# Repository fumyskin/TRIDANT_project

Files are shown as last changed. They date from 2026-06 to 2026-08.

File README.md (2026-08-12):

# TRIDANT project
 
**T**wo-band **R**adiation-pattern **I**nstrument for **D**irectional **ANT**enna
characterization — a portable system that measures and visualizes 2D antenna
radiation patterns (azimuth and elevation cuts) in two bands:
 
- **GNSS L1** — ~1.575 GHz
- **V2X** — ~5.9 GHz
A hand-aimed sensor head streams raw RF power and orientation over Bluetooth Low
Energy to a host computer, which calibrates the samples, bins them by angle, and
draws live polar radiation-pattern plots.
 
> Built for the IEEE AP-S Student Design Contest.
https://photos.app.goo.gl/PjTwk66SGvRQrtHY9
---
 
## Repository layout
 
```
TRIDANT_project/
├── platformio.ini            # firmware build config (board, libs, flags)
├── src/
│   ├── main.cpp              # FreeRTOS task setup, entry point
│   └── tasks/
│       ├── ble_task.*        # NimBLE server, Sample notify
│       ├── bno_task.*        # BNO085 orientation → boresight vector
│       ├── sensor_task.*     # AD8317 ADC read
│       └── sample.h          # wire contract (byte-locked to protocol.py)
├── test/
│   └── protocol_test.cpp     # wire-format sanity checks
│
├── gui_app/
│   ├── tridant_gui.py        # live BLE GUI (matplotlib polar plots)
│   ├── capture_ble.py        # BLE → CSV logger (raw mV, re-calibratable)
│   ├── protocol.py           # Sample unpack + host-side calibration profiles
│   └── parameters.md         # per-band R_MIN/R_MAX and calibration notes
├── plotter_scripts/
│   ├── plotter.py            # offline log → polar pattern plots
│   └── interpolation_AD.py   # interpolation experiments
├── scripts/
│   └── logger.sh             # serial (USB) → band-split log files
├── 3d_models/                # printing models for the components used in the demo
│
├── logs/      logs_ble/      # captured sessions (serial / BLE)
└── plots/                    # rendered pattern figures
``` 
---
 
## How it works
 
The firmware stays deliberately thin: it emits **raw sensor values only** — the
AD8317 detector output in millivolts plus a quaternion-derived boresight
orientation. All calibration, coordinate transformation, and visualization live
**host-side**, in Python. This keeps captured logs re-calibratable after the
fact and means changing bands never requires reflashing.
 
```
  ┌─────────────────────────┐        BLE          ┌──────────────────────────┐
  │  ESP32-C6 (CodeCell)    │   15-byte Sample    │  Host (Python)           │
  │                         │  ───────────────▶  │                          │
  │  BNO085 IMU  → orient.  │  phi, theta, elev,  │  calibrate mV → dBm      │
  │  AD8317 LPD  → mV       │  mv, cal            │  bin by angle → polar    │
  └─────────────────────────┘                     │ live plot / CSV / offline│
                                                  └──────────────────────────┘
```
The wire format is a single source of truth shared across the language boundary (`src/tasks/sample.h` on the firmware side, `gui_app/protocol.py` on the host side), verified with `static_assert` in C++ and `struct.calcsize` in Python:
 
```cpp
struct Sample { float phi, theta, elev;  uint16_t mv;  uint8_t cal; }  // 15 bytes
protocol.SAMPLE_FMT = "<fffHB"                                          // 15 bytes
```

---

## Prerequisites
 
- **Firmware:** [PlatformIO](https://platformio.org/) (CLI or the VS Code
  extension). A CodeCell / ESP32-C6 board on a USB port (e.g. `/dev/ttyACM0`).
- **Host tooling:** Python 3.9+ and a working BLE adapter.

---

## Repository Installation

Clone the repository:
 
```bash
git clone https://github.com/fumyskin/TRIDANT_project.git
cd TRIDANT_project
```
 
---

The repo has two independent halves — set up whichever you need.
 
### 1. Firmware (PlatformIO)
 
`platformio.ini` pins the board (`esp32-c6-devkitm-1`), the pioarduino
ESP32 platform, and the required libraries (NimBLE-Arduino, CodeCell), so the
dependencies install themselves on the first build.
 
```bash
pip install platformio          # skip if you use the VS Code extension
 
pio run                         # build (downloads libs on first run)
pio run -t upload               # flash over USB
pio device monitor              # serial monitor @ 115200
```

### 2. Host tooling (Python)
 
Use a virtual environment so the dependencies stay isolated:
 
```bash
python -m venv .venv
source .venv/bin/activate        # Windows: .venv\Scripts\activate
 
pip install -r requirements.txt
```
 
---
 
## Usage
### Live pattern GUI
 
Real-time polar plots over BLE. Scans for the sensor head, connects, and draws
azimuth and elevation cuts as you sweep.
 
```bash
python gui_app/tridant_gui.py
```
 
Keys: `c` clears the accumulated pattern, `q` quits.

### Capture raw samples over BLE
 
Logs raw wire values (mV, not dBm) to CSV so the session stays re-calibratable
and re-plottable later.
 
```bash
python gui_app/capture_ble.py                      # timestamped CSV
python gui_app/capture_ble.py -o dipole_az.csv     # explicit file
python gui_app/capture_ble.py --dbm --band GNSS    # add dBm column + live peak
```

### Capture over serial (USB)
 
Logs the CodeCell's serial output into band-specific files under `logs/`.
Run it from inside `scripts/` (the default log directory is `../logs`):
 
```bash
cd scripts
./logger.sh GNSS                 # fallback band = GNSS
./logger.sh V2X /dev/ttyACM0     # explicit port
```
 
### Plot a captured log offline
 
```bash
python plotter_scripts/plotter.py logs/GNSS.log --normalize
python plotter_scripts/plotter.py logs/GNSS.log logs/V2X.log
```
 
---
## Calibration & configuration
 
Calibration is host-owned. Per-band detector profiles (slope in mV/dB and
intercept in mV) live in `gui_app/protocol.py`:
 
```python
PROFILES = {
    "GNSS_1G575": {"slope_mv_per_db": -25.0, "intercept_mv": 510.0},
    "V2X_5G9":    {"slope_mv_per_db": -25.0, "intercept_mv": 608.0},
}
```
 
The conversion is `P_dBm = (mv − intercept_mv) / slope_mv_per_db`. For
**normalized** pattern shape, intercept errors cancel and only the slope
matters; a **fixed absolute** radial axis additionally needs a calibrated
intercept and a known peak power.
 
To set the radial limits (`R_MIN` / `R_MAX`) for a band, find the peak by
sweeping the main beam with `capture_ble.py --dbm --band <BAND>` and reading the
live `peak` value. See **`gui_app/parameters.md`** for the full per-band
procedure and the current tuning values.
 
---
 
## Wire protocol
 
| Field | Type | Meaning |
|---|---|---|
| `phi` | float32 | azimuth (deg) |
| `theta` | float32 | polar/elevation angle (deg) |
| `elev`  | float32 | elevation (deg) |
| `mv` | uint16 | AD8317 detector output (millivolts)  |
| `cal` | uint8 | IMU calibration status |
 
Packed little-endian as `"<fffHB"` = **15 bytes**. Any change here must be made
in both `src/tasks/sample.h` and `gui_app/protocol.py`, or the two sides will
disagree.
 
---
 
## License

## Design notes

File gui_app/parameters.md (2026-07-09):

# PARAMETERS FOR CORRECT USAGE OF GUI ON GNSS AND V2X

# FINDING R_MIN, R_MAX
 1) GNSS: run `python capture_ble.py --dbm --band GNSS`, perform a complete azimuth sweep and check the `peak` value : that's your `R_MAX` to be inserted in the `tridant_gui.py`
 2) V2X: run `python capture_ble.py --dbm --band V2X`, perform a perform a complete azimuth sweep and check the `peak` value : that's your `R_MAX` to be inserted in the `tridant_gui.py`

## GNSS
`capture_ble.py`:
 1) set `DEFAULT_PROFILE` to `"GNSS_1G575"`

`tridant_gui.py`:
 1) set `PROFILE` to `"GNSS_1G575"`
 2) set `R_MAX = -5.5`  and `R_MIN = -60.0`
 3) set proper GNSS calibration based on the LPD model used:
    if ADP317: slope = -22 mv/db; intercept = 315 mv
    if ADP318: 

## V2X
`capture_ble.py`:
 1) set `DEFAULT_PROFILE` to `"V2X_5G9"`

`tridant_gui.py`:
 1) set `PROFILE` to `"V2X_5G9"`
 2) set `R_MAX = `  and `R_MIN = -60.0` 
 3) set proper GNSS calibration based on the LPD model used:
    ADP317: slope = -22 mv/db; intercept = 352 mv
    ADP318:

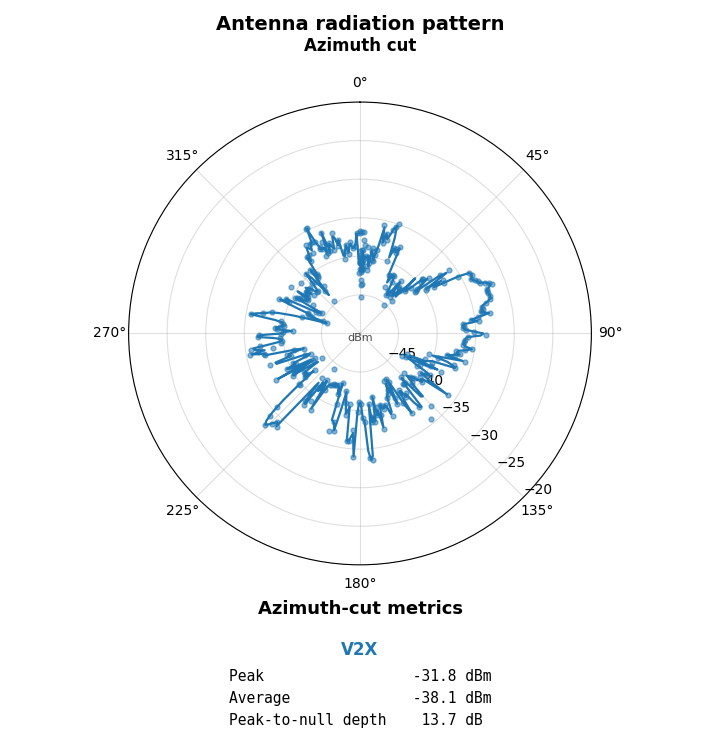
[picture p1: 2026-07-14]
plots/batch_final2/V2X_01vcutv.png

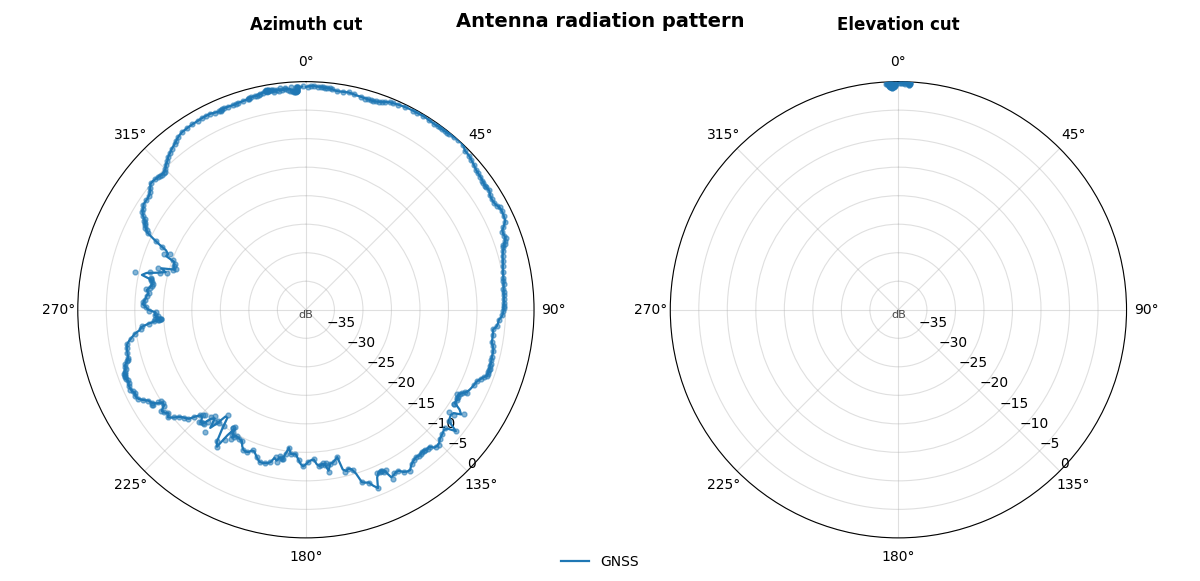
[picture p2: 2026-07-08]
plots/batch2/GNSS_03v.png

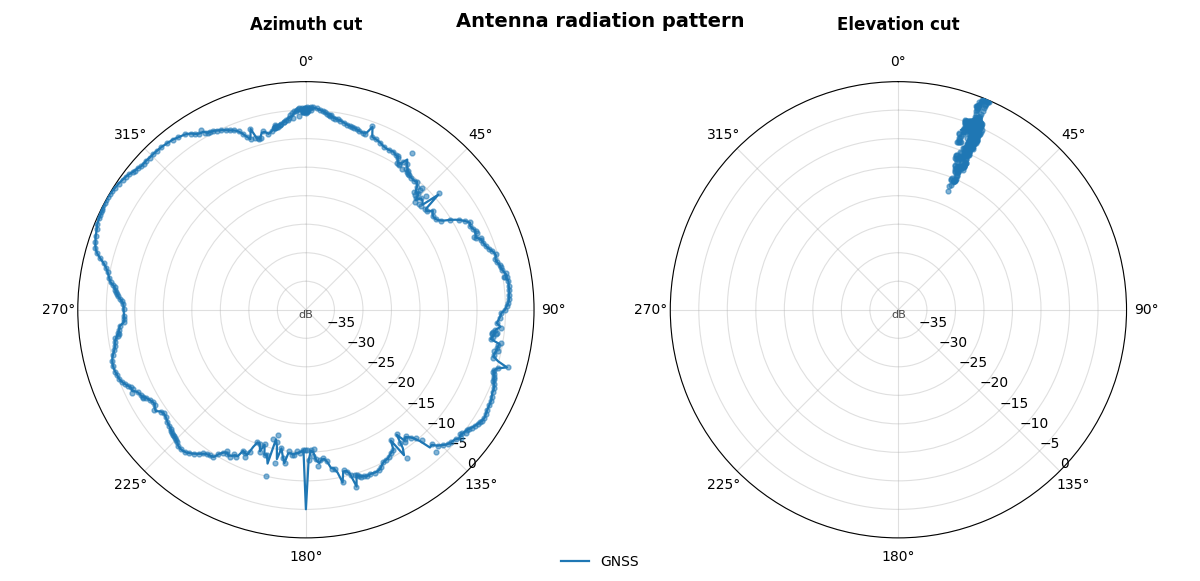
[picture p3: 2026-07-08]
plots/batch2/GNSS_02h.png

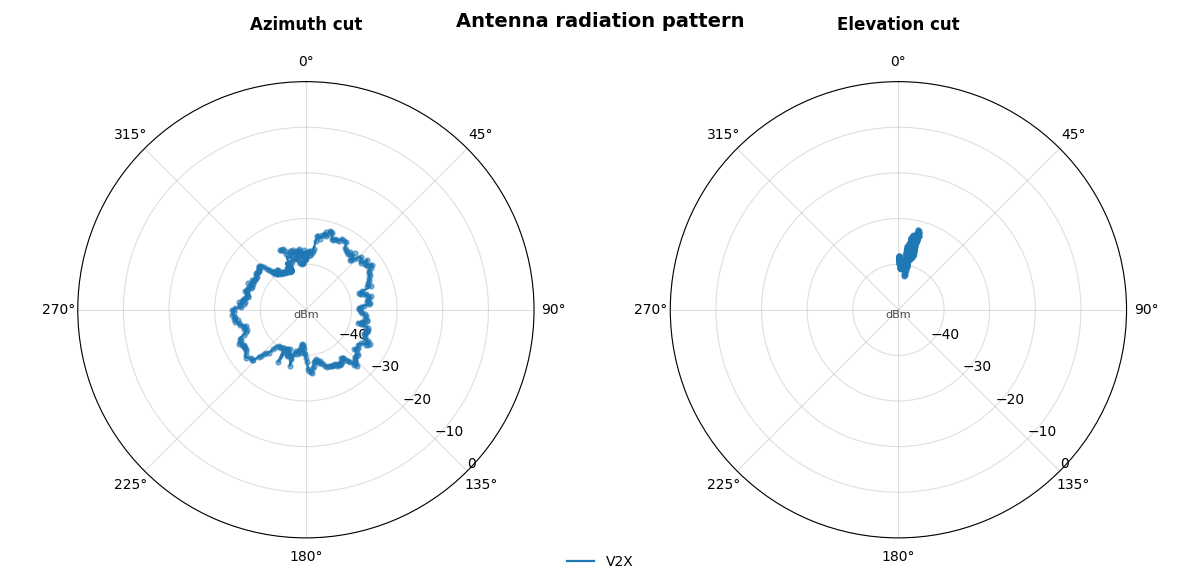
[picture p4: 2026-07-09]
plots/batch_final1.5/V2Xhcutv.png

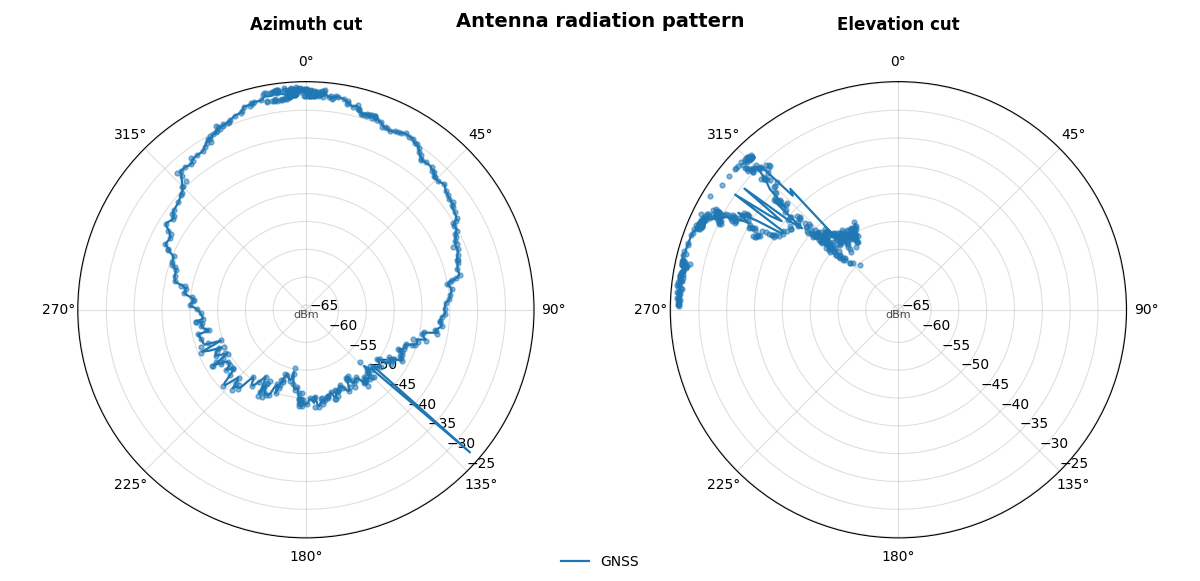
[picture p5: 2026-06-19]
plots/batch1/GNSS_04_nhc_elevation_full.png

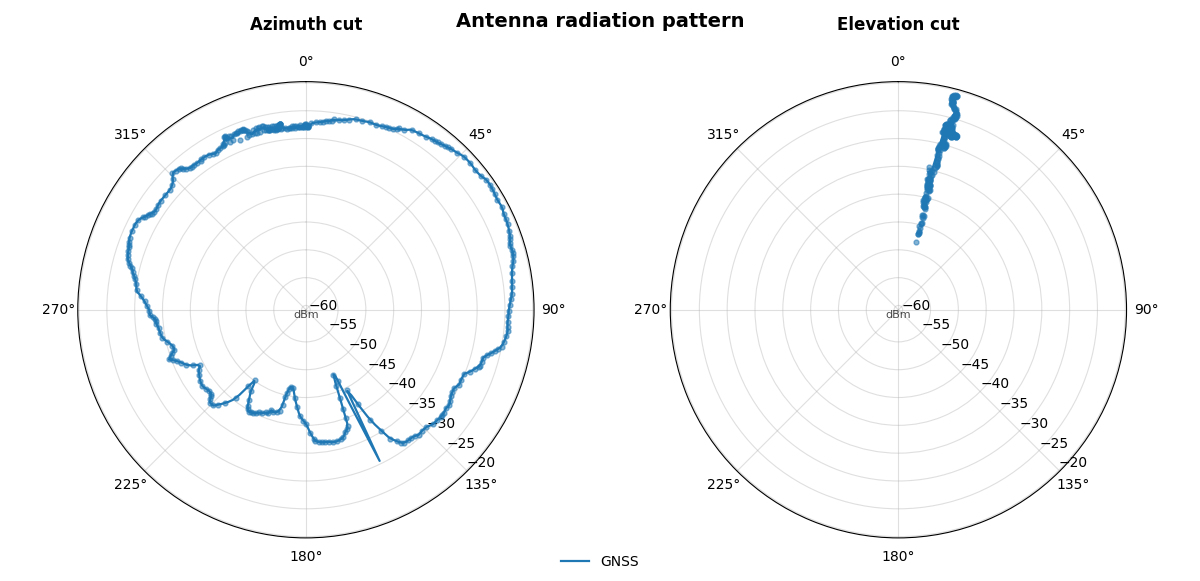
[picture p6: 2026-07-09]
plots/batch_final/GNSS_06h.png

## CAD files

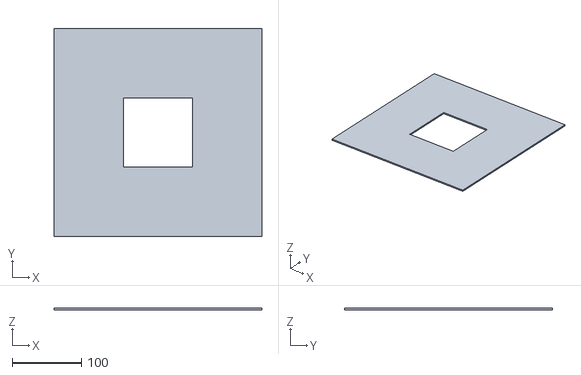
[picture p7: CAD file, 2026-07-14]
3d_models/DRA_GROUNDPLANE.stl
300.0 x 300.0 x 2.50

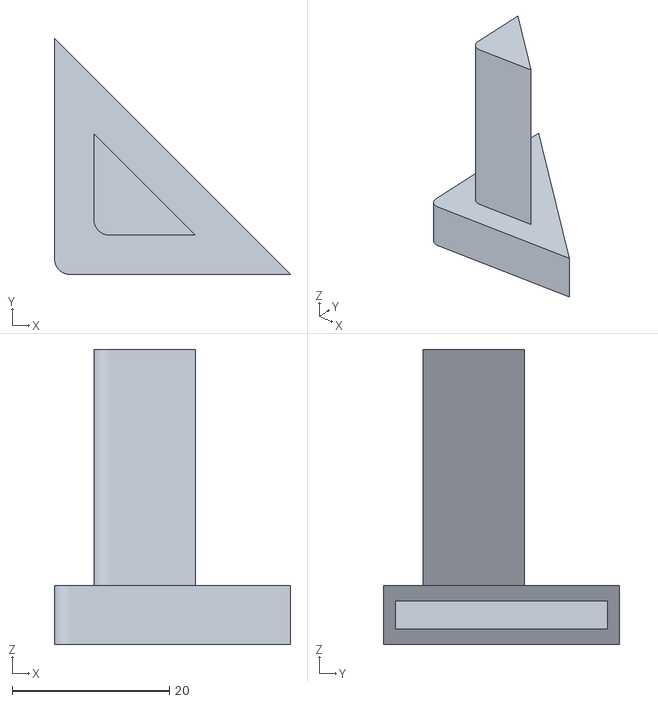
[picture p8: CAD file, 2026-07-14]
3d_models/DRA_SUPPORT.stl
30.0 x 30.0 x 37.5

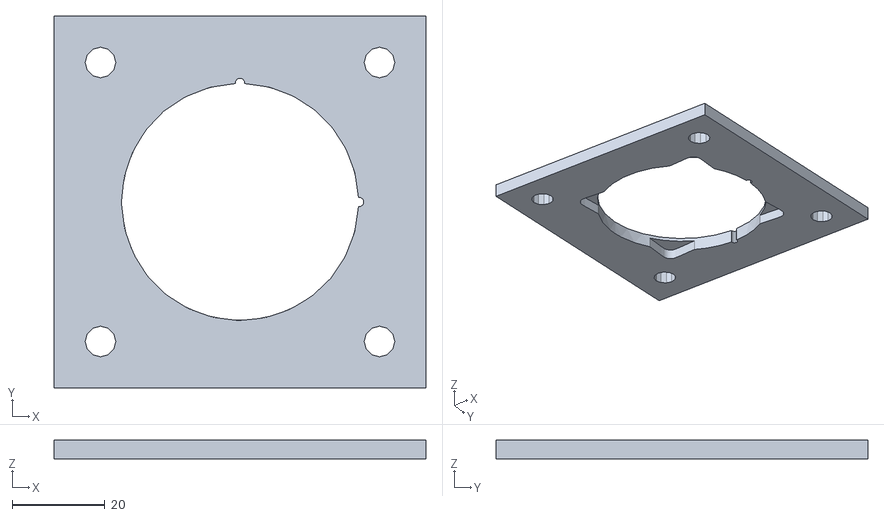
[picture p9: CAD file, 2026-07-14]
3d_models/DRA_FIXING_PLATE.stl
80.0 x 80.0 x 4.00

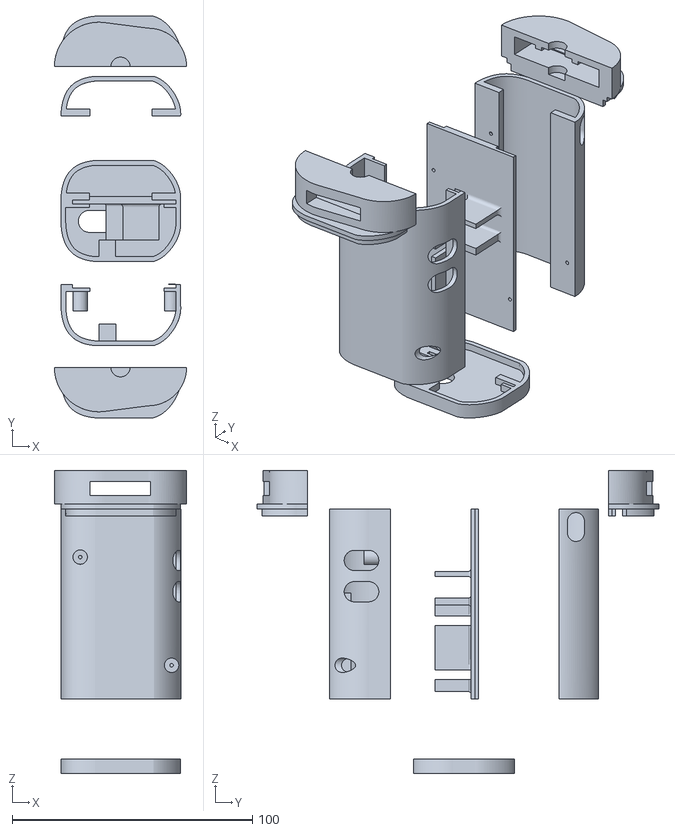
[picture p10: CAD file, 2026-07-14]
3d_models/ANTENNA_RECEIVER_HANDLE.stl
55.0 x 167.0 x 126.0

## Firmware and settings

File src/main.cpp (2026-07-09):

#include <Arduino.h>
#include <tasks/sensor_task.h>
#include "tasks/bno_task.h"
#include "tasks/ble_task.h"
#include <CodeCell.h>
#include <Wire.h>

// might be redundant
//constexpr float LPD_SLOPE_MV_PER_DB = -25.0f; // mV/dBm
//constexpr float LPD_INTERCEPT_MV    = 500.0f; //mV

//static float mv_to_dbm(int mv) {
//    return ((float)mv - LPD_INTERCEPT_MV) / LPD_SLOPE_MV_PER_DB;
//}

BnoSample ang;

void setup() {
    Serial.begin(115200);
    delay(2000);
    Serial.println("BOOT");

    sensor_task_start();
    bno_task_init();
    bno_task_calibrate(8000, 3);   // ~8 s DEAD STILL on a table — gyro ZRO settles here
    bno_task_capture_zero();
    bno_task_start();

    ble_task_start(); // create task + queue
    ble_task_setup_ble(); // build service + characteristic
    ble_task_start_advertising(); // go discoverable

    Serial.println("tasks started");
    Serial.println("phi_deg,theta_deg,elev_deg,P_dBm,mv,cal");   // <- added ,cal
}

void loop() {
    int mv = 0;
    bool haveP   = sensor_task_get_latest_mv(&mv);
    bool haveAng = bno_task_get_latest(&ang);
    uint32_t acc = bno_task_cal_accuracy();

    //remove mv_to_dbm for correct measurenments
    if (haveP && haveAng) {
        Serial.printf("%.1f,%.1f,%.1f,%d,%u\n",
                      ang.azimuth_deg,
                      ang.polar_deg,
                      ang.elevation_deg,
                      mv,
                      acc);
        if (ble_task_has_clients()){
            Sample s;
            s.phi_deg = ang.azimuth_deg;
            s.theta_deg = ang.polar_deg;
            s.elev_deg = ang.elevation_deg;
            s.mv = (uint16_t)mv;
            s.acc = (uint8_t)acc;
            ble_task_send_sample(s);
        }
    } else {
        Serial.printf("waiting: haveP=%d haveAng=%d cal=%u\n", haveP, haveAng, acc);
    }
    delay(100);   // ~10 Hz logging, matches the BNO Run(10) rate
}

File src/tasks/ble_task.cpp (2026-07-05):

#include "ble_task.h"
#include <Arduino.h>
#include <NimBLEDevice.h>
#include <freertos/FreeRTOS.h>
#include <freertos/task.h>
#include <freertos/queue.h>

#define MAX_CONNECTIONS 1
#define SERVICE_UUID        "97dcc426-d11e-476e-95e2-79f064720640"
#define CHARACTERISTIC_UUID "aae3a4f0-8e88-4bd0-8047-c6a8c2312a3d"
#define DEVICE_NAME         "TRIDANT"   

namespace {
    NimBLEServer*         pServer = nullptr;
    NimBLECharacteristic* pChar   = nullptr;
    NimBLEAdvertising*    pAdv     = nullptr;

    TaskHandle_t  bleTaskHandle = nullptr;
    QueueHandle_t bleQueue      = nullptr;

    uint16_t connIDs[MAX_CONNECTIONS];
    volatile int connCount = 0;

    enum BleCommand : uint8_t {
        BLE_START_SETUP,
        BLE_START_ADV,
        BLE_STOP_ADV,
        BLE_TX
    };

    // One message type flows through the queue. `sample` is meaningful
    // only for BLE_TX; lifecycle commands ignore it.
    struct BleMsg {
        BleCommand cmd;
        Sample     sample;
    };
}

class ServerCallbacks : public NimBLEServerCallbacks {
    void onConnect(NimBLEServer* server, NimBLEConnInfo& connInfo) override {
        uint16_t conn_id = connInfo.getConnHandle();
        if (connCount < MAX_CONNECTIONS) connIDs[connCount++] = conn_id;
        Serial.printf("Client connected, conn id: %u\n", conn_id);
        // No re-advertise here: single slot stays quiet once connected.
    }

    void onDisconnect(NimBLEServer* server, NimBLEConnInfo& connInfo, int reason) override {
        uint16_t conn_id = connInfo.getConnHandle();
        for (int i = 0; i < connCount; i++) {
            if (connIDs[i] == conn_id) {
                for (int j = i; j < connCount - 1; j++) connIDs[j] = connIDs[j + 1];
                connCount--;
                break;
            }
        }
        Serial.printf("Client disconnected (reason %d), conn id: %u\n", reason, conn_id);
        NimBLEDevice::startAdvertising();   // allow reconnect between sweeps
    }
};

static void bleTask(void* parameter) {
    NimBLEDevice::init(DEVICE_NAME);
    pServer = NimBLEDevice::createServer();
    pServer->setCallbacks(new ServerCallbacks());

    NimBLEService* pService = nullptr;
    BleMsg msg;

    for (;;) {
        if (xQueueReceive(bleQueue, &msg, portMAX_DELAY) != pdTRUE) continue;

        switch (msg.cmd) {
            case BLE_START_SETUP:
                pService = pServer->createService(SERVICE_UUID);
                pChar = pService->createCharacteristic(
                    CHARACTERISTIC_UUID,
                    NIMBLE_PROPERTY::READ | NIMBLE_PROPERTY::NOTIFY
                );
                pService->start();
                pAdv = NimBLEDevice::getAdvertising();
                pAdv->addServiceUUID(SERVICE_UUID);
                pAdv->enableScanResponse(false);
                break;

            case BLE_START_ADV:
                Serial.println("BLE_START_ADV");
                NimBLEDevice::startAdvertising();
                break;

            case BLE_STOP_ADV:
                Serial.println("BLE_STOP_ADV");
                NimBLEDevice::stopAdvertising();
                break;

            case BLE_TX:
                if (pChar && connCount > 0) {
                    pChar->setValue((uint8_t*)&msg.sample, sizeof(Sample));
                    pChar->notify();
                }
                break;
        }
    }
}

// ---- public API ----
void ble_task_start() {
    bleQueue = xQueueCreate(8, sizeof(BleMsg));
    xTaskCreate(bleTask, "BLE Task", 4096, nullptr, 1, &bleTaskHandle);
}

void ble_task_setup_ble() {
    BleMsg m{ BLE_START_SETUP, {} };
    xQueueSend(bleQueue, &m, portMAX_DELAY);
    Serial.println("Setting up the BLE");
    delay(1);
}

void ble_task_start_advertising() {
    BleMsg m{ BLE_START_ADV, {} };
    xQueueSend(bleQueue, &m, portMAX_DELAY);
    Serial.println("Starting BLE advertisement");
    delay(1);
}

void ble_task_send_sample(const Sample& s) {
    BleMsg m{ BLE_TX, s };
    // Non-blocking: drop on backpressure rather than stall the 10 Hz loop.
    xQueueSend(bleQueue, &m, 0);
}

bool ble_task_has_clients() { return connCount > 0; }

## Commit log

2026-05-31 Added BNO task (working), modified SENSOR task for ADC parallel communication, fixed dependencies problems
2026-05-31 Added BNO task (working), modified SENSOR task for ADC parallel communication
2026-06-01 fixed mv reading from adc to avoid squeezing
2026-06-15 Added warmup algorithm, changed parametrization for ADC
2026-06-16 changed calibration for ADP8318
2026-06-17 modified adc calibration, added quick python script for data verifications
2026-06-17 implemented calibration without magnetometer, added correct calibration to avoid drifting
    [main.cpp]
2026-06-18 corrected ble task for sending string of data instead of single value, added protocol in python for correct calibration
    [ble_task.cpp, main.cpp]
2026-06-19 corrected plotter, added aid scripts, logger and measurenment plots
    [main.cpp]
2026-07-05 real-time gui: fixed binning, sampling, calibration, plotting
    [ble_task.cpp, main.cpp]
2026-07-08 BLE capture script of raw data
    [tridant_20260708_095335.csv]
2026-07-08 final polished to gui and protocol
    [GNSS_01h.csv, GNSS_01v.csv, GNSS_02h.csv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]
2026-07-09 changes in calibration and tolerance values
2026-07-09 fixed static gui and live gui data
    [GNSS_05h.csv, GNSS_05v.csv, GNSS_06h.csv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]
2026-07-13 added_3d models
    [ANTENNA_RECEIVER_HANDLE.stl, DRA_FIXING_PLATE.stl, DRA_GROUNDPLANE.stl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]
2026-07-14 readme updated
    [V2X_01hcutv.csv, V2X_01hcutv3x.csv, V2X_01try.csv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]
